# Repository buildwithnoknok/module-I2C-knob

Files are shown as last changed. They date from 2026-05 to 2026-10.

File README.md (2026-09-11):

# noknok Knob

An I²C-controlled rotary encoder module for the noknok ecosystem.
Designed for smooth, reliable user input: volume control, menu navigation, parameter adjustment, and more.

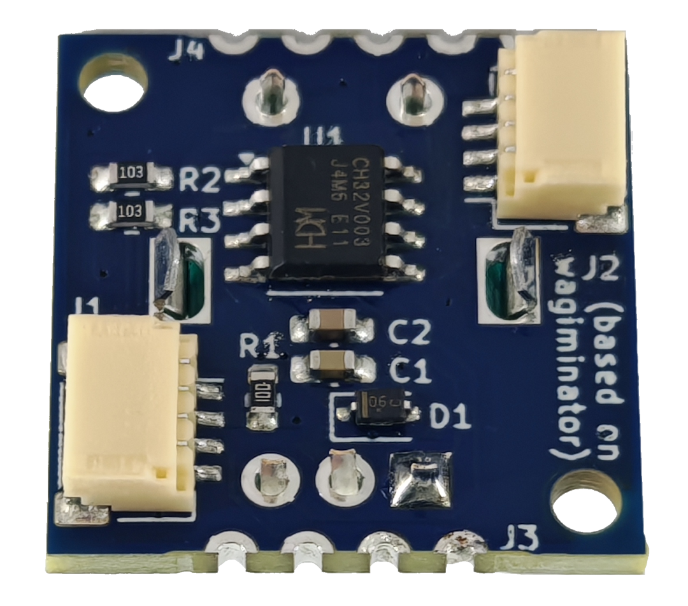
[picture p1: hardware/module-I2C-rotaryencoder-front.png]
Front

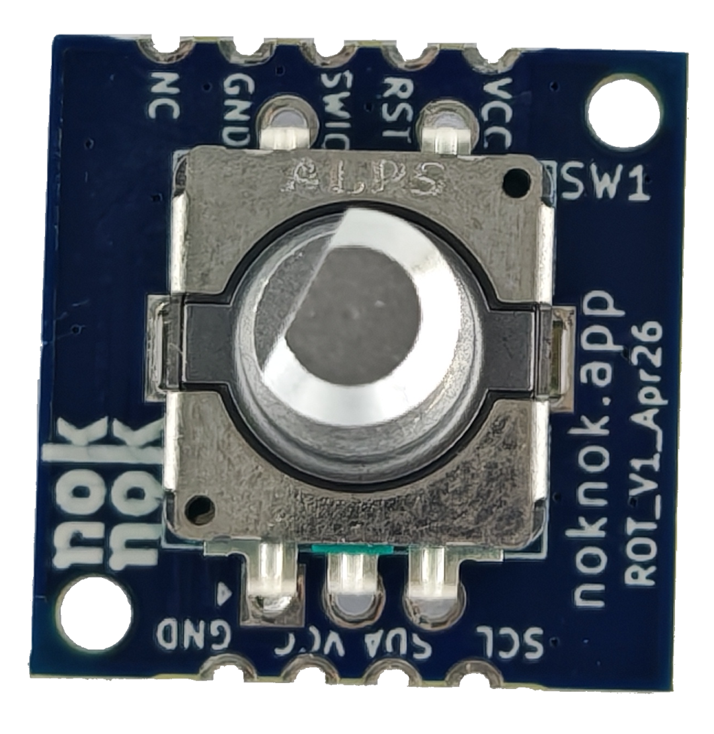
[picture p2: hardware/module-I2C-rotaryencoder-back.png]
Back


---

## Overview

The **noknok Knob** uses a CH32V003J4M6 microcontroller to read a mechanical EC11 rotary encoder with integrated push button. It exposes position, delta, and button state over I²C using the standard noknok JST SH 4-pin connector. The I²C address is assigned dynamically at boot by the noknok Conductor — no address conflicts when using multiple modules.

Typical use cases:
- Volume / brightness control
- Menu navigation
- Parameter tuning (speed, mode, color)
- General UI input for kits and finished products

---

## Hardware

| Property | Value |
|---|---|
| PCB size | 20 × 20 mm |
| MCU | CH32V003J4M6 (SOP-8) |
| Encoder | EC11 rotary encoder with push button |
| Connector | JST SH 4-pin (Qwiic / STEMMA QT compatible) |
| Supply voltage | 3.3 V |
| Logic voltage | 3.3 V |
| Hardware version | v2.0 |

### Pinout (CH32V003J4M6 SOP-8)

| Pin name | Function |
|---|---|
| PA2 | Encoder A (active LOW, internal pull-up) |
| PD6 / PA1 | Encoder B (active LOW, read as PA1) |
| PC4 | Push button S2 (active LOW; S1 and C are grounded) |
| PC1 | I²C SDA |
| PC2 | I²C SCL |
| PD1 / PD4 / PD5 | SWDIO — firmware flashing (3-pad pogo pads, J3) + status LED (D2, active LOW) share the PD1/SWIO net |

### noknok Connector (JST SH 4-pin)

| Pin | Signal |
|---|---|
| 1 | GND |
| 2 | 3.3 V |
| 3 | SDA |
| 4 | SCL |

---

## Firmware

**Version: v2.3.0 (bootloader‑hosted)**

### Enumeration

The module uses the standard noknok dynamic enumeration protocol — no hardcoded I²C address.

**→ Full protocol spec:** [Ecosystem / software / enumeration.md](https://github.com/buildwithnoknok/Ecosystem/blob/main/software/enumeration.md)

### I²C Protocol (normal operation)

**Pico reads 4 bytes:**

| Byte | Content |
|---|---|
| 0–1 | Signed 16-bit position, big-endian |
| 2 | Signed 8-bit delta since last read (auto-clears on read) |
| 3 | Button state: `0x01` = pressed, `0x00` = released |

> Button state is suppressed for 150 ms after any rotation to prevent false triggers from mechanical shaft coupling.

**Pico writes:**

| Command | Effect |
|---|---|
| `[0x10]` | Reset position to 0 |
| `[0x11, posH, posL]` | Set position to signed 16-bit value |
| `[0xB0]` | Enter bootloader — reset into the I²C bootloader for an OTA firmware update (see [Firmware](#firmware-1)) |
| `[0xB1]` | Get version — standard noknok command; the next read returns 4 version bytes (see below) |

**Version read** — `GET_VERSION` (`0xB1`) is a **noknok ecosystem-standard** command (the `0xB0`–`0xBF` range is reserved for standard commands across every module). Write `0xB1`, then read **4 bytes**: `[PROTOCOL_VERSION, FW_MAJOR, FW_MINOR, FW_PATCH]` = `[0x01, 2, 3, 0]`. Lets the Conductor compare the installed version against the version required by the product manifest. **→ Full spec:** [Ecosystem / software / readme.md §5](https://github.com/buildwithnoknok/Ecosystem/blob/main/software/readme.md#5-standard-system-commands)

### Encoder counting

- Hardware EXTI interrupts on both edges of PA1 and PA2 catch every quadrature transition immediately.
- A sub-step accumulator divides by 2: **2 raw transitions = 1 position count**, giving exactly **1 count per physical detent**.

---

## Python Driver

Part of the [noknok Ecosystem](https://github.com/buildwithnoknok/Ecosystem) — see `software/pico/noknok.py`.

```python
from noknok import Conductor

c = Conductor()
c.enumerate()                  # discovers all modules (~3 s)

knob = c.knob[0]               # first knob by discovery order
# or: knob = c.role["volume"]  # by role name after setup_roles()

s = knob.read()
if s is not None:
    print(s.position)          # signed int, cumulative turns
    print(s.delta)             # change since last read (auto-clears)
    print(s.pressed)           # True if button held down

knob.reset()                   # set position to 0
knob.set_position(50)          # set to any signed 16-bit value
```

---

## Firmware

**v2.3.0 runs under the shared noknok I²C bootloader** ([module-I2C-bootloader](https://github.com/buildwithnoknok/module-I2C-bootloader)) — the module can be re‑flashed **over the I²C bus** (no SWDIO cable in the field). The application is linked at the `0x1400` offset (`app.ld`) above the 5 KB stage-0 + stage-1 bootloader (layout 2) and reserves the top 16 B of RAM for the bootloader handoff cell. Command `0xB0` drops the running module into the bootloader for an update.

```bash
cd firmware/src
make build   # compile the offset-linked application -> knob_firmware.bin
```

> ch32fun must be installed at `../ch32fun/` relative to `firmware/src/` — see [cnlohr/ch32v003fun](https://github.com/cnlohr/ch32v003fun) for setup.

Flashing: normally over I²C from the Pico (`module_flasher.py` in `brain-Pico`). A blank board needs the bootloader SWD‑flashed once first. SWD remains the unbrickable backstop — see *Recovery & SWD flashing* in the [bootloader README](https://github.com/buildwithnoknok/module-I2C-bootloader#recovery--swd-flashing). `make flash` here still does a one‑off SWD flash of the app for bench bring‑up.

---

## Changelog

### v2.3.0 — app base 0x1400 (bootloader layout 2)
Relinked at the `0x1400` flash offset (bootloader **layout 2**: 1 KB stage-0 + 4 KB stage-1 below the app; was `0x1000`). Firmware behaviour unchanged. **Not compatible with the legacy monolithic bootloader or a layout-1 stage-1** — such a module gets stage-0 + stage-1 v1.1.0 over SWD first, then this app over I²C. See [module-I2C-bootloader](https://github.com/buildwithnoknok/module-I2C-bootloader).

### v2.2.0 — watchdog + boot-health handshake (DEV-31)
Runs the independent watchdog (~2 s, kicked every main-loop pass) and writes `0` to `0x200007F8` the moment its I²C address is assigned — the app-health handshake with the stage-1 bootloader. Stage-1 counts watchdog resets and parks the module (error 7, rescued by the Conductor by UID) after three in a row, instead of booting a broken app forever. Contract: [Ecosystem / software / bootloader-update.md §3](https://github.com/buildwithnoknok/Ecosystem/blob/main/software/bootloader-update.md). No protocol or command change.

### v2.1 and earlier
See the git history.

## Status

| Item | Status |
|---|---|
| Hardware | v2.0 complete |
| Firmware | v2.3.0 complete (bootloader‑hosted, I²C OTA) |
| Python driver | Complete (`NoknokKnob` in [Ecosystem repo](https://github.com/buildwithnoknok/Ecosystem/tree/main/software/pico)) |
| Documentation | Complete |

---

## License

- Firmware / code: MIT — see [LICENSE](LICENSE).
- Hardware (schematics, PCB layout, fab files): CC BY-SA 4.0 — see [LICENSE-hardware](LICENSE-hardware).

## Trademarks

**noknok** is a registered trademark in Switzerland (Swissreg 1300007033).

Qwiic is a registered trademark of SparkFun Electronics, Inc. STEMMA QT is a
trademark of Adafruit Industries, LLC. Both are named here only to state
connector compatibility - noknok is not affiliated with, endorsed by, or
sponsored by either company.
---

---

## Safety & Liability

noknok hardware is an electronic device and a DIY/maker kit. You assemble, modify, flash, power, and operate it at your own risk, and it is provided as is, without warranty. See the full notice: [License, Safety & Liability](https://buildwithnoknok.github.io/safety-and-license/).

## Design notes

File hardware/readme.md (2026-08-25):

# Hardware — noknok Knob

Hardware design files for the noknok Knob module (CH32V003J4M6 — I2C rotary encoder with integrated push button).

- KiCad project: `kicad/I2C_knob.*`
- Schematic (PDF): `module-I2C-knob-Schematics.pdf`
- BOM: `module_I2C-knob-BOM.xls`
- Board renders: `module-I2C-rotaryencoder-front.png`, `module-I2C-rotaryencoder-back.png` *(pre-V2 renders — pending re-export)*

Hardware is licensed CC BY-SA 4.0 (see `../LICENSE-hardware`). Connector, flashing and mounting standards follow the [noknok Ecosystem guidelines](https://github.com/buildwithnoknok/Ecosystem) (electrical + mechanical).

---

## Hardware Change Record

### v2.0 — changes from v1.0
- **Status indicator LED on PD1** (in parallel with the SWIO flashing line — zero extra GPIO). Active-low: `+3V3_PROT → R2 (2.2 kΩ) → D2 anode; D2 cathode → PD1/SWIO`. Driven by the bootloader (off = app running, slow pulse = updating/recovering, solid = error). Parts: red 0603 LED (LCSC C2286) + 2.2 kΩ 0603 (LCSC C4190).
- **Removed both castellated edge pads** — the 5-pin flashing edge and the redundant I2C edge (unreliable to contact). I2C is via the JST-SH (Qwiic) connectors J1/J2 only.
- **New flashing interface (J3)** — noknok flash pads (`noknok_FlashPads_I2C-module_1x3_M2.5`): 3 single-side SMD pogo pads (GND / SWIO / VCC) plus an embedded M2.5 keyed mounting hole, from the noknok KiCad library in the Ecosystem repo. Pad row is offset toward the keyed hole (not centered) so a 180°-flipped clamp contact can't seat and reverse-power the board.
- **Second mounting hole (H1)** — plain `noknok_MountingHole_2.5mm_M2.5`, diagonally opposite the flash-pad hole, center (2.25, 2.25) mm from the board corner.
- **Removed the on-board I²C pull-up resistors** (previously R2/R3) — pull-ups now live on the host (Conductor), not per module (avoids stacking on the shared bus). The host must provide the bus pull-ups (proposed 3.3 kΩ); a noknok pull-up PCB covers third-party hosts that lack them. See the [I²C Pull-up Resistor Strategy ADR](https://noknokdev.atlassian.net/wiki/spaces/SD/pages/82280449). *(Note: `R2` is reused below for the new status-LED resistor — it is not the old pull-up.)*
- **R1 (VDD series) stays 10 Ω** — the knob has no spiky load on VDD (unlike the buzzer's beep-current 10Ω→1Ω fix), so the standard default is unchanged.

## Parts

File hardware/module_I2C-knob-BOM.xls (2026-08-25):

Item # | *Designator | *Qty | Manufacturer | *Mfg Part # | Description / Value | Vendor Part # | *Package/Footprint | Substitute
1 | C1 | 1 | YAGEO | CC0603MRX5R8BB106 | 10uF / CAP CER 10uF 25V X5R 0603 | C596327 | C_0603_1608Metric_Pad1.08x0.95mm_HandSolder | SAMSUNG『 』CL10A106KP8NNNC『 』C19702
2 | C2 | 1 | YAGEO | CC0603KRX7R9BB104 | 0.1uF / CAP CER 100nF 50V X7R 0603 | C14663 | C_0603_1608Metric_Pad1.08x0.95mm_HandSolder | SAMSUNG『 』CL10B104KA8NNNC『 』C1590
3 | D1 | 1 | onsemi | MM3Z3V6T1G | D_Zener | C116949 | D_SOD-323 | ROHM『 』UDZVTE-173.6B『 』C209558
4 | D2 | 1 | Hubei KENTO Elec | KT-0603R | LED RED WATER CLEAR 0603 SMD | C2286 | 0603
5 | J1, J2 | 2 | JST | SM04B-SRSS-TB(LF)(SN) | JST 4 Pin Qwiic I2C Connector | C160404 | JST_SH_SM04B-SRSS-TB_1x04-1MP_P1.00mm_Horizontal
6 | R1 | 1 | YAGEO | RC0603JR-0710RL | 10R | C109317 | R_0603_1608Metric | Viking『 』ARG03FTC0100『 』C217691
7 | R2 | 1 | YAGEO | RC0603JR-072K2L | 2.2k | C113303 | R_0603_1608Metric | Viking『 』ARG03FTC2201『 』C217937
8 | SW1 | 1 | ALPSALPINE | EC11E18244AU | RotaryEncoder_Switch | C202365 | RotaryEncoder_Alps_EC11E-Switch_Vertical_H20mm
9 | U1 | 1 | WCH(Jiangsu Qin Heng) | CH32V003J4M6 | CH32V003J4M6 | C5346354 | JEITA_SOIC-8_3.9x4.9mm_P1.27mm

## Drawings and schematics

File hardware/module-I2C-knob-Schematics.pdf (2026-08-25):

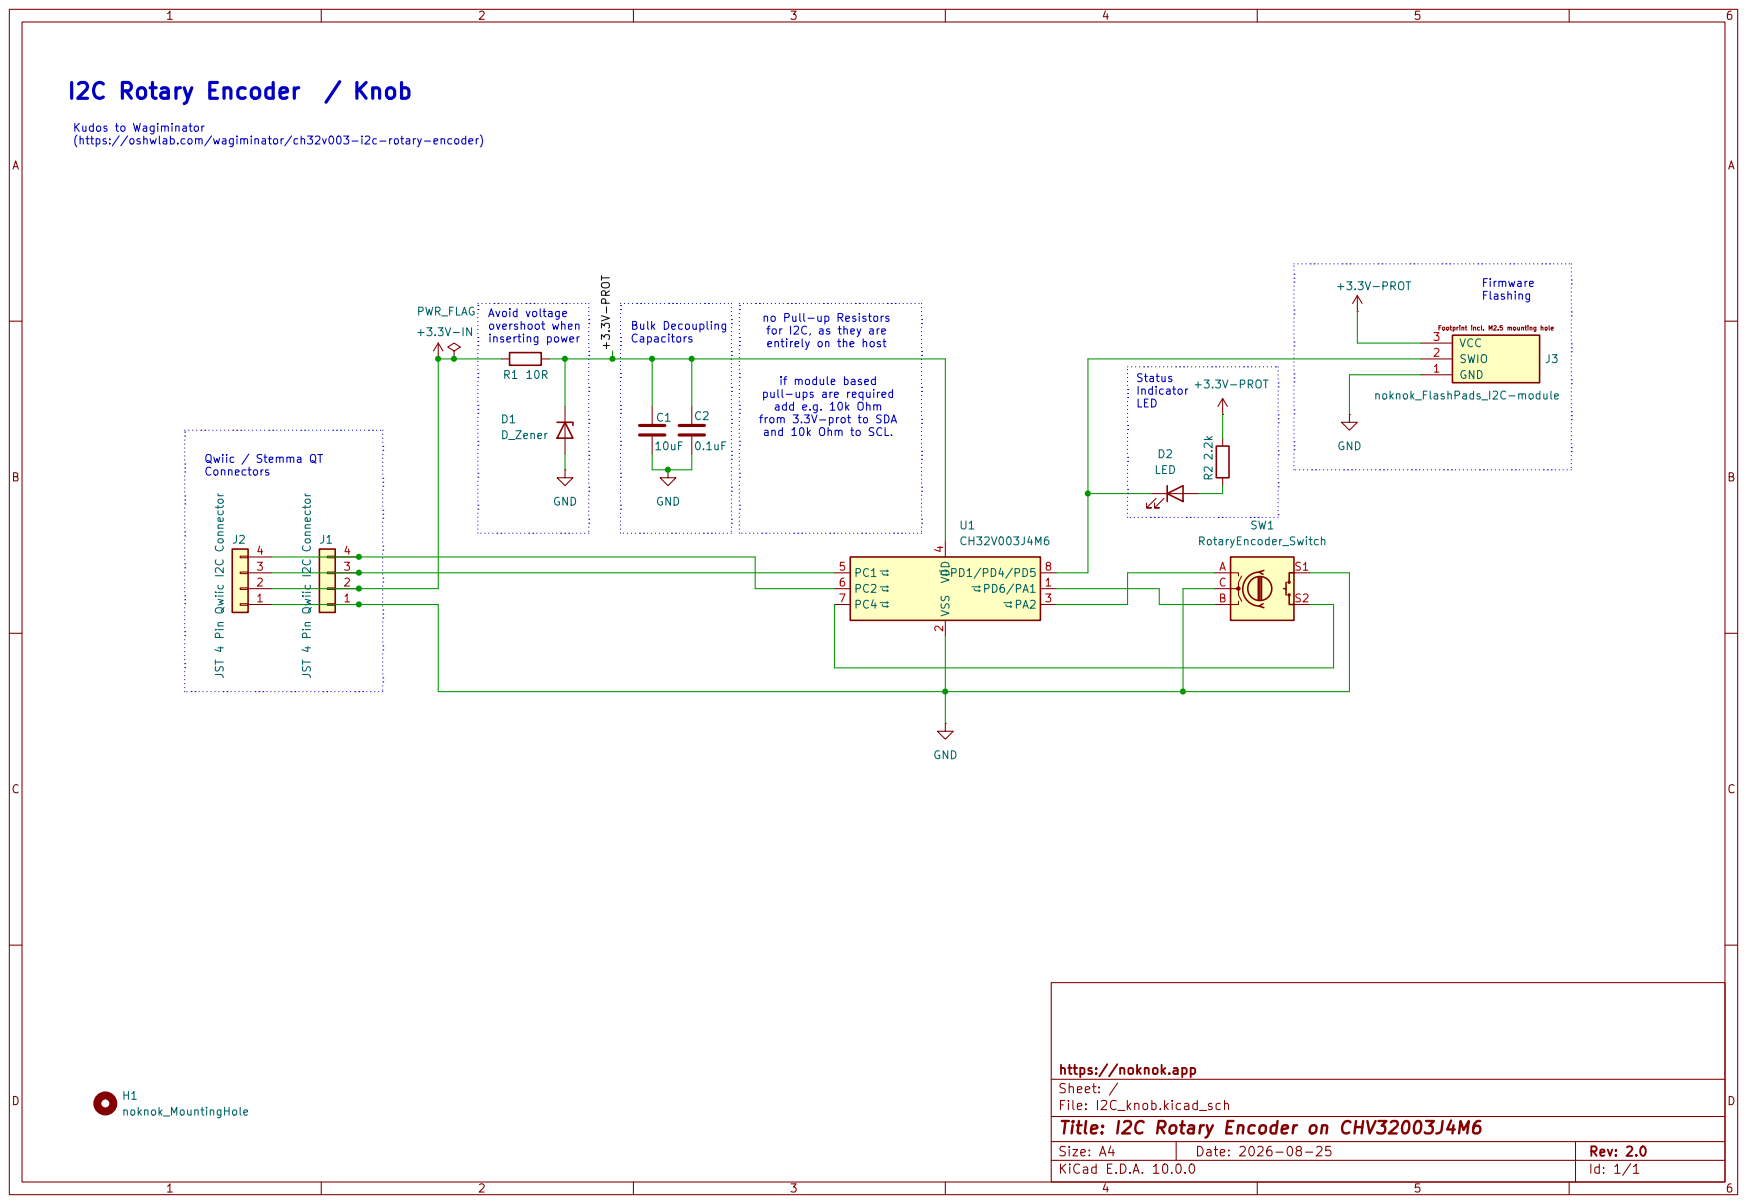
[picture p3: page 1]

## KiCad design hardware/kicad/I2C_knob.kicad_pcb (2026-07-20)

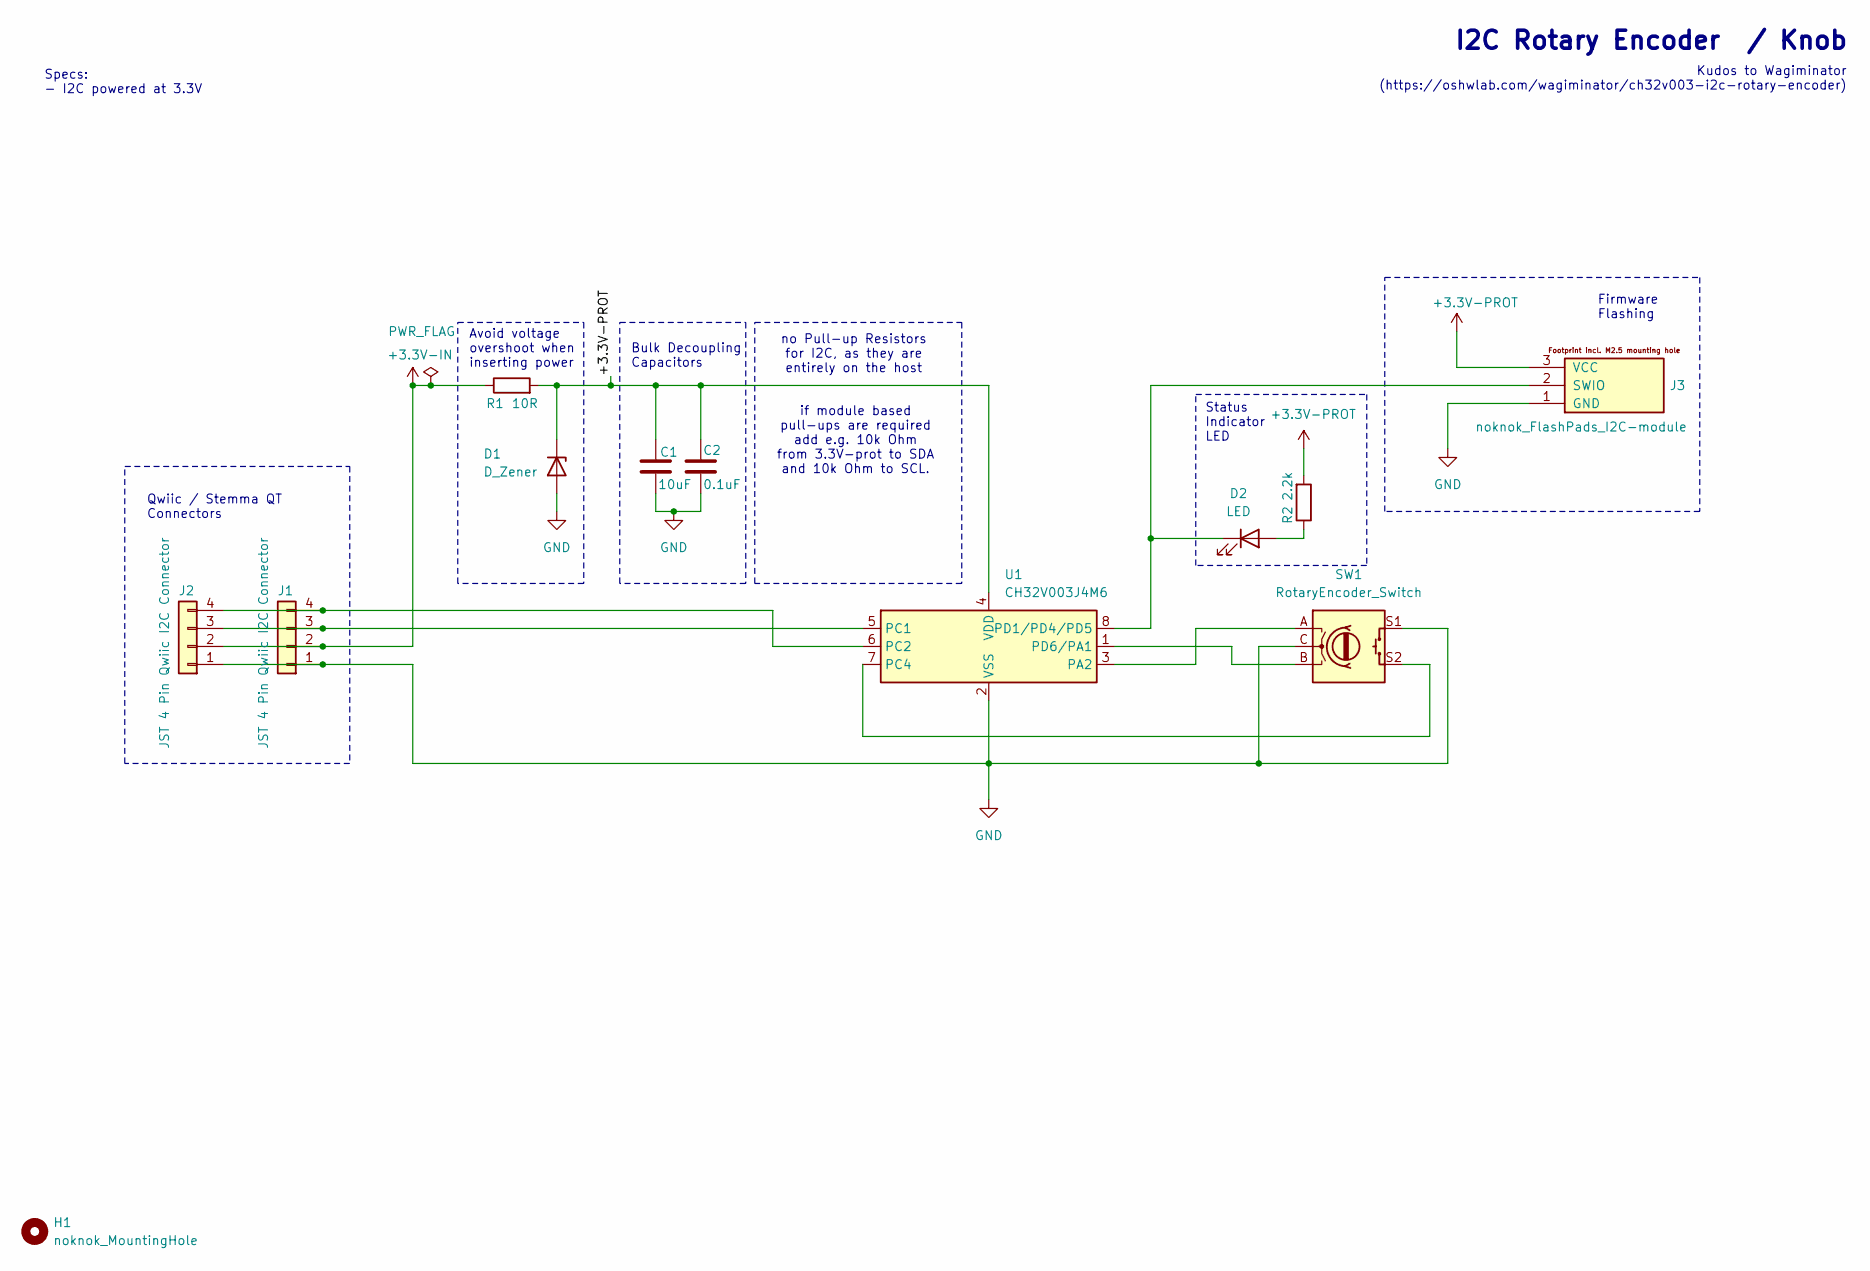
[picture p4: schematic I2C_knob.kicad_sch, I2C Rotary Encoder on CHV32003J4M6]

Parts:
C1: 10uF; C_0603_1608Metric_Pad1.08x0.95mm_HandSolder
C2: 0.1uF; C_0603_1608Metric_Pad1.08x0.95mm_HandSolder
D1: D_Zener; D_SOD-323
D2: LED; LED_0603_1608Metric
H1: noknok_MountingHole; noknok_MountingHole_2.5mm_M2.5
J1, J2: JST 4 Pin Qwiic I2C Connector; JST_SH_SM04B-SRSS-TB_1x04-1MP_P1.00mm_Horizontal
J3: noknok_FlashPads_I2C-module; noknok_FlashPads_I2C-module_1x3_M2.5
R1: 10R; R_0603_1608Metric
R2: 2.2k; R_0603_1608Metric
SW1: RotaryEncoder_Switch; RotaryEncoder_Alps_EC11E-Switch_Vertical_H20mm
U1: CH32V003J4M6; JEITA_SOIC-8_3.9x4.9mm_P1.27mm

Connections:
+3.3V-IN: J1.2, J2.2, R1.1
+3.3V-PROT: C1.1, C2.1, D1.1 (K), J3.3 (VCC), R1.2, R2.2, U1.4 (VDD)
GND: C1.2, C2.2, D1.2 (A), J1.1, J2.1, J3.1 (GND), SW1.C, SW1.S1, U1.2 (VSS)
unnamed: D2.2 (A), R2.1
unnamed: D2.1 (K), J3.2 (SWIO), U1.8 (PD1/PD4/PD5)
unnamed: J1.3, J2.3, U1.5 (PC1)
unnamed: J1.4, J2.4, U1.6 (PC2)
unnamed: SW1.A, U1.3 (PA2)
unnamed: SW1.S2, U1.7 (PC4)
unnamed: SW1.B, U1.1 (PD6/PA1)

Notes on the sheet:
Avoid voltage overshoot when inserting power
Specs: - I2C powered at 3.3V
I2C Rotary Encoder / Knob
if module based pull-ups are required add e.g. 10k Ohm from 3.3V-prot to SDA and 10k Ohm to SCL.
Status Indicator LED
no Pull-up Resistors for I2C, as they are entirely on the host
Firmware Flashing
Qwiic / Stemma QT Connectors
Kudos to Wagiminator (https://oshwlab.com/wagiminator/ch32v003-i2c-rotary-encoder)
Bulk Decoupling Capacitors

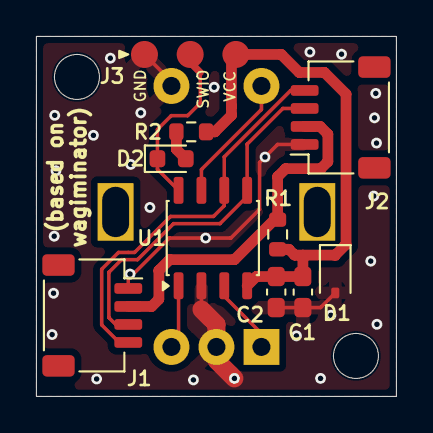
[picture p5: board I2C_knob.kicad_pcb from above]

Board: 2 copper layers, 20.0 x 20.0 mm, 12 parts (1 on the bottom side), 10 nets.

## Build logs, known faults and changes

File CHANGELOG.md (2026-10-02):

# Changelog - noknok Knob module firmware

Newest first. One entry per version bump, written in the same commit as the bump. Format:
`## <version> - <date>` then `- DEV-xx - what changed and why. Breaking: yes/no.`
Convention: Confluence "Development Conventions" (SD space, page 120160257).

## Baseline - 2026-10-02

- Changelog starts here. Current: knob firmware 2.3.0 (released 2026-09-11). Earlier history: git log and the README.

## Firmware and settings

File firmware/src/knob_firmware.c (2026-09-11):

/*
 * noknok Knob Module Firmware  v2.2.0
 *
 * v2.2.0: DEV-31 hardening C — independent watchdog + boot-attempt handshake
 *   with stage-1 (clears the counter once an I2C address is assigned).
 * CH32V003J4M6 (SOP-8)  |  Stack: cnlohr/ch32fun
 *
 * ── Hardware ─────────────────────────────────────────────────────────────
 *   PA2          Encoder A (active LOW, internal pull-up)
 *   PD6/PA1      Encoder B (active LOW, internal pull-up; read as PA1 via GPIOA)
 *   PC4          Encoder push button S2 (active LOW; S1 and C are grounded)
 *   PC1          I2C SDA
 *   PC2          I2C SCL
 *
 * ── Encoder counting ─────────────────────────────────────────────────────
 *   EXTI interrupts on both edges of PA1 and PA2 (EXTI1 + EXTI2, port A).
 *   Gray-code lookup table → ±1 per quadrature transition.
 *   A standard EC11 with 4 pulses/detent gives 4 counts per click.
 *
 * ── Button behaviour ─────────────────────────────────────────────────────
 *   50 ms debounce. Suppressed for 150 ms after any rotation (mechanical
 *   coupling between shaft and SW pin causes false triggers during turns).
 *
 * ── Enumeration protocol ─────────────────────────────────────────────────
 *   Identical to noknok Buzzer v3.1.
 *   Staging address : 0x7F
 *   Runtime address : assigned by Conductor (0x08–0x77)
 *
 *   1. Conductor reads 10 bytes from 0x7F:
 *        [UID 0..7]   64-bit hardware UID
 *        [0x02]       MODULE_TYPE (knob)
 *        [CRC8]       CRC8 of bytes 0–8
 *
 *   2. Conductor writes to 0x7F:
 *        [0x1D, new_addr]   ASSIGN — module switches to new_addr
 *
 * ── Normal operation protocol ────────────────────────────────────────────
 *   I2C address: assigned at runtime
 *
 *   Pico READS 4 bytes:
 *     [posH, posL]   signed 16-bit position, big-endian
 *     [delta]        signed 8-bit change since last read (auto-cleared)
 *     [btn_state]    0x01 if button pressed, 0x00 if released
 *                    Always 0x00 within 150 ms of rotation.
 *
 *   Pico WRITES:
 *     [0x10]              RESET — set position to 0
 *     [0x11, posH, posL]  SET POSITION — set position to given value
 *     [0xB0]              ENTER BOOTLOADER (I2C OTA update)
 *     [0xB1]              GET VERSION — next read returns 4 version bytes
 *
 *   Pico READS (after 0xB1):
 *     4 bytes: [PROTOCOL_VER, FW_MAJOR, FW_MINOR, FW_PATCH]
 *
 *   GET_VERSION (0xB1) is a noknok ecosystem-standard command (range
 *   0xB0–0xBF reserved). See Ecosystem/software/readme.md §5.
 */

#include "ch32fun.h"
#include <stdint.h>

/* ═══════════════════════════════════════════════════════════════════════════
 * CONFIGURATION
 * ═══════════════════════════════════════════════════════════════════════════ */

#define ENUM_ADDR       0x7F
#define MODULE_TYPE     0x02    /* 0x02 = Rotary Encoder / Knob */
#define REG_ASSIGN_ADDR 0x1D
#define CMD_RESET_POS   0x10
#define CMD_SET_POS     0x11
#define CMD_ENTER_BOOTLOADER 0xB0   /* reset into the I2C bootloader for OTA update */
#define CMD_GET_VERSION 0xB1        /* report [PROTOCOL_VERSION, FW_MAJOR, FW_MINOR, FW_PATCH] */

/* ── Version reporting (noknok standard command, DEV-1) ──────────────────────
 * PROTOCOL_VERSION = which noknok protocol/API this module speaks — NOT the
 * firmware version. Bumped only when the shared protocol changes. The
 * FW_VERSION_* triple is this module's firmware semver; keep it equal to the
 * release tag. Reported on a GET_VERSION (0xB1) read. */
#define PROTOCOL_VERSION 0x01
#define FW_VERSION_MAJOR 2
#define FW_VERSION_MINOR 3
#define FW_VERSION_PATCH 0

/* Bootloader handoff cell — top 16 B of RAM, reserved by app.ld (stack ends
 * below it). Writing this magic then warm-resetting drops the module into the
 * shared noknok I2C bootloader (flash mode at 0x7E). SRAM survives a warm reset.
 * Magic + address MUST match noknok_bootloader. */
#define BL_MAGIC_CELL   (*(volatile uint32_t *)0x200007F0U)
#define BL_MAGIC_ENTER  0x6E6B4231U   /* "nkB1" */

/* ── App health handshake with stage-1 (DEV-31 hardening C) ──────────────────
 * Stage-1 counts every boot of this app in a no-init RAM cell and stops booting
 * it after three consecutive warm resets without the app ever proving itself,
 * parking the module in the bootloader at 0x7E so the host can push a good
 * image instead. That turns "a broken app with a valid CRC is booted forever"
 * into "a broken app gets three tries". Two things make it work here:
 *   - the independent watchdog, so a hang becomes a warm reset (~2 s), and
 *   - clearing the counter the moment we KNOW we are healthy: an I2C address
 *     has been assigned, i.e. enumeration completed, i.e. I2C works.
 * Address and tag must match noknok_stage1. */
#define BOOT_ATTEMPT_CELL (*(volatile uint32_t *)0x200007F8U)

static void iwdg_init(void)
{
    /* LSI ~128 kHz / 64 = 2 kHz; reload 4095 -> ~2.05 s. Hardware starts LSI. */
    IWDG->CTLR = 0x5555;  IWDG->PSCR = 4;
    IWDG->CTLR = 0x5555;  IWDG->RLDR = 0xFFF;
    IWDG->CTLR = 0xCCCC;  /* start — cannot be stopped except by reset */
}
static inline void iwdg_kick(void) { IWDG->CTLR = 0xAAAA; }

#define UID_ADDR        ((volatile uint8_t*)0x1FFFF7E8)
#define UID_LEN         8

#define BTN_DEBOUNCE_MS         50
#define BTN_ROTATION_LOCKOUT_MS 150


/* ═══════════════════════════════════════════════════════════════════════════
 * STATE
 * ═══════════════════════════════════════════════════════════════════════════ */

typedef enum {
    DEV_BOOT_WAITING,
    DEV_ENUM_READY,
    DEV_ASSIGNING,
    DEV_ASSIGNED,
} DeviceState;

static volatile DeviceState dev_state = DEV_BOOT_WAITING;
static volatile uint32_t    ms_tick   = 0;
static volatile uint8_t     new_addr  = 0;
static volatile uint8_t     version_pending = 0; /* set in ISR on 0xB1; next read returns version */

/* Encoder */
static volatile int16_t  enc_position    = 0;
static volatile int8_t   enc_delta       = 0;
static volatile uint32_t last_rotation_ms = 0;
static volatile uint8_t  enc_last_ab     = 0;
static volatile int8_t   enc_sub         = 0;  /* sub-step: 2 raw transitions = 1 count */

/* Lookup table: enc_table[(prev<<2)|curr] → +1, -1, or 0 */
static const int8_t enc_table[16] = {
     0, -1,  1,  0,
     1,  0,  0, -1,
    -1,  0,  0,  1,
     0,  1, -1,  0
};

/* Button */
static volatile uint8_t  btn_state        = 0;
static          uint8_t  btn_raw_last      = 0;
static          uint32_t btn_last_change_ms = 0;

/* I2C receive */
#define RX_BUF_SIZE 8
static volatile uint8_t rx_buf[RX_BUF_SIZE];
static volatile uint8_t rx_len    = 0;
static volatile uint8_t cmd_ready = 0;

/* I2C transmit */
#define TX_BUF_SIZE 10
static volatile uint8_t tx_buf[TX_BUF_SIZE];
static volatile uint8_t tx_len = 0;
static volatile uint8_t tx_idx = 0;

/* Backoff */
static uint32_t backoff_ms;
static uint32_t enum_ready_start_ms = 0;


/* ═══════════════════════════════════════════════════════════════════════════
 * CRC8  (polynomial 0x07)
 * ═══════════════════════════════════════════════════════════════════════════ */

static uint8_t crc8(const uint8_t *data, uint8_t len)
{
    uint8_t crc = 0x00;
    for (uint8_t i = 0; i < len; i++) {
        crc ^= data[i];
        for (uint8_t j = 0; j < 8; j++)
            crc = (crc & 0x80) ? (crc << 1) ^ 0x07 : (crc << 1);
    }
    return crc;
}


/* ═══════════════════════════════════════════════════════════════════════════
 * BACKOFF TIMER  —  proper FNV-1a, identical to Buzzer v3.1
 * ═══════════════════════════════════════════════════════════════════════════ */

static uint32_t fnv_hash(uint32_t h)
{
    volatile uint8_t *uid = UID_ADDR;
    for (uint8_t i = 0; i < UID_LEN; i++) {
        h ^= uid[i];
        h *= 16777619UL;
    }
    return h;
}

static void calc_backoff(void)
{
    backoff_ms = (fnv_hash(2166136261UL) % 2500) + 300;
}

static uint32_t calc_rebackoff_ms(void)
{
    return ms_tick + (fnv_hash(ms_tick) % 500) + 50;
}


/* ═══════════════════════════════════════════════════════════════════════════
 * BUILD RESPONSES
 * ═══════════════════════════════════════════════════════════════════════════ */

static void build_uid_response(void)
{
    volatile uint8_t *uid = UID_ADDR;
    for (uint8_t i = 0; i < UID_LEN; i++)
        tx_buf[i] = uid[i];
    tx_buf[8] = MODULE_TYPE;
    tx_buf[9] = crc8((const uint8_t*)tx_buf, 9);
    tx_len = 10;
    tx_idx = 0;
}

static void build_data_response(void)
{
    int16_t pos = enc_position;

    /* Read enc_delta and clear it atomically here in the ISR.
     * Clearing here (not in the main loop) prevents a race where encoder
     * transitions arriving between this read and a deferred main-loop clear
     * would be silently discarded. Any transitions after this point will
     * correctly accumulate into enc_delta for the next read. */
    int8_t dlt  = enc_delta;
    enc_delta   = 0;

    /* Suppress button during rotation lockout — shaft mechanics couple into SW */
    uint8_t btn = ((ms_tick - last_rotation_ms) >= BTN_ROTATION_LOCKOUT_MS)
                  ? btn_state : 0;
    tx_buf[0] = (uint8_t)((pos >> 8) & 0xFF);
    tx_buf[1] = (uint8_t)(pos & 0xFF);
    tx_buf[2] = (uint8_t)dlt;
    tx_buf[3] = btn;
    tx_len = 4;
    tx_idx = 0;
}

/* 4-byte GET_VERSION response: [PROTOCOL_VERSION, FW_MAJOR, FW_MINOR, FW_PATCH] */
static void build_version_response(void)
{
    tx_buf[0] = PROTOCOL_VERSION;
    tx_buf[1] = FW_VERSION_MAJOR;
    tx_buf[2] = FW_VERSION_MINOR;
    tx_buf[3] = FW_VERSION_PATCH;
    tx_len = 4;
    tx_idx = 0;
}


/* ═══════════════════════════════════════════════════════════════════════════
 * GPIO INIT
 * ═══════════════════════════════════════════════════════════════════════════ */

static void encoder_gpio_init(void)
{
    RCC->APB2PCENR |= RCC_APB2Periph_GPIOA | RCC_APB2Periph_GPIOC;

    /* PA1 (ENC_B) and PA2 (ENC_A): input with pull-up */
    GPIOA->CFGLR &= ~((0xF << (1 * 4)) | (0xF << (2 * 4)));
    GPIOA->CFGLR |=  ((0x8 << (1 * 4)) | (0x8 << (2 * 4)));
    GPIOA->BSHR   =  (1 << 1) | (1 << 2);

    /* PC4: input with pull-up (button S2, active LOW; S1+C are grounded) */
    GPIOC->CFGLR &= ~(0xF << (4 * 4));
    GPIOC->CFGLR |=  (0x8 << (4 * 4));
    GPIOC->BSHR   =  (1 << 4);
}

static inline uint8_t read_enc_ab(void)
{
    /* A = PA2 (active low), B = PA1 (active low) — per Wagiminator reference.
     * Invert both so 1 means "encoder contact closed". */
    uint8_t a = !((GPIOA->INDR >> 2) & 1);   /* PA2 = ENC_A */
    uint8_t b = !((GPIOA->INDR >> 1) & 1);   /* PA1 = ENC_B */
    return (a << 1) | b;
}

static inline uint8_t read_btn_raw(void)
{
    return ((GPIOC->INDR >> 4) & 1) ? 0 : 1;   /* PC4, active LOW */
}


/* ═══════════════════════════════════════════════════════════════════════════
 * EXTI  —  hardware interrupts on both edges of PA1 (EXTI1) and PA2 (EXTI2)
 *   Catches every quadrature transition immediately, regardless of main loop
 *   speed. Both EXTI1 and EXTI2 share EXTI7_0_IRQn on CH32V003.
 * ═══════════════════════════════════════════════════════════════════════════ */

static void exti_encoder_init(void)
{
    RCC->APB2PCENR |= RCC_APB2Periph_AFIO;

    /* Route EXTI1 and EXTI2 to port A (bits [3:2] and [5:4] = 00 = PA) */
    AFIO->EXTICR &= ~((0x3 << 2) | (0x3 << 4));

    /* Enable interrupts on both rising and falling edges for EXTI1 and EXTI2 */
    EXTI->INTENR |= (1 << 1) | (1 << 2);
    EXTI->RTENR  |= (1 << 1) | (1 << 2);
    EXTI->FTENR  |= (1 << 1) | (1 << 2);

    NVIC_EnableIRQ(EXTI7_0_IRQn);
}

void EXTI7_0_IRQHandler(void) __attribute__((interrupt));
void EXTI7_0_IRQHandler(void)
{
    if (EXTI->INTFR & ((1 << 1) | (1 << 2)))
    {
        uint8_t ab  = read_enc_ab();
        uint8_t idx = (enc_last_ab << 2) | ab;
        int8_t  dir = enc_table[idx];

        if (dir != 0)
        {
            last_rotation_ms = ms_tick;
            enc_sub += dir;
            if (enc_sub >= 2)      { enc_sub -= 2; enc_position++; enc_delta++; }
            else if (enc_sub <= -2){ enc_sub += 2; enc_position--; enc_delta--; }
        }

        enc_last_ab = ab;
        EXTI->INTFR = (1 << 1) | (1 << 2);   /* clear pending flags */
    }
}


/* ═══════════════════════════════════════════════════════════════════════════
 * TIM2  —  1 ms tick
 * ═══════════════════════════════════════════════════════════════════════════ */

static void tim2_init(void)
{
    RCC->APB1PCENR |= RCC_APB1Periph_TIM2;
    TIM2->PSC      = 47;
    TIM2->ATRLR    = 999;
    TIM2->DMAINTENR = TIM_IT_Update;
    TIM2->SWEVGR   = TIM_UG;
    TIM2->CTLR1   |= TIM_CEN;
    NVIC_EnableIRQ(TIM2_IRQn);
}

void TIM2_IRQHandler(void) __attribute__((interrupt));
void TIM2_IRQHandler(void) { TIM2->INTFR = 0; ms_tick++; }


/* ═══════════════════════════════════════════════════════════════════════════
 * I2C SLAVE
 * ═══════════════════════════════════════════════════════════════════════════ */

static void i2c_slave_init(uint8_t addr)
{
    RCC->APB2PCENR |= RCC_APB2Periph_GPIOC;
    RCC->APB1PCENR |= RCC_APB1Periph_I2C1;

    GPIOC->CFGLR &= ~(0xF << (1 * 4)); GPIOC->CFGLR |= (0xF << (1 * 4));
    GPIOC->CFGLR &= ~(0xF << (2 * 4)); GPIOC->CFGLR |= (0xF << (2 * 4));

    I2C1->CTLR1 |=  I2C_CTLR1_SWRST;
    I2C1->CTLR1 &= ~I2C_CTLR1_SWRST;

    I2C1->CTLR2  = 48;
    I2C1->CKCFGR = 240;
    I2C1->OADDR1 = ((uint16_t)addr << 1);

    I2C1->CTLR2 |= I2C_CTLR2_ITEVTEN | I2C_CTLR2_ITBUFEN | I2C_CTLR2_ITERREN;
    I2C1->CTLR1 |= I2C_CTLR1_ACK | I2C_CTLR1_PE;

    NVIC_EnableIRQ(I2C1_EV_IRQn);
    NVIC_EnableIRQ(I2C1_ER_IRQn);
}

static void i2c_switch_addr(uint8_t addr)
{
    I2C1->CTLR1 &= ~I2C_CTLR1_PE;
    I2C1->OADDR1 = ((uint16_t)addr << 1);
    I2C1->CTLR1 |= I2C_CTLR1_ACK | I2C_CTLR1_PE;
}


/* ═══════════════════════════════════════════════════════════════════════════
 * I2C EVENT ISR
 * ═══════════════════════════════════════════════════════════════════════════ */

void I2C1_EV_IRQHandler(void) __attribute__((interrupt));
void I2C1_EV_IRQHandler(void)
{
    uint32_t star1 = I2C1->STAR1;
    uint32_t star2 = I2C1->STAR2;

    if (star1 & I2C_STAR1_ADDR)
    {
        rx_len = 0;
        I2C1->CTLR1 |= I2C_CTLR1_ACK;

        if (star2 & I2C_STAR2_TRA)
        {
            if (dev_state == DEV_ENUM_READY)
            {
                build_uid_response();
                I2C1->DATAR = tx_buf[tx_idx++];
            }
            else if (version_pending)
            {
                /* Previous write was GET_VERSION → return the 4 version bytes */
                version_pending = 0;
                build_version_response();
                I2C1->DATAR = tx_buf[tx_idx++];
            }
            else
            {
                build_data_response();
                I2C1->DATAR = tx_buf[tx_idx++];
            }
        }
        return;
    }

    if (star1 & I2C_STAR1_RXNE)
    {
        uint8_t b = (uint8_t)I2C1->DATAR;
        if (rx_len < RX_BUF_SIZE) rx_buf[rx_len++] = b;
        return;
    }

    if (star1 & I2C_STAR1_TXE)
    {
        I2C1->DATAR = (tx_idx < tx_len) ? tx_buf[tx_idx++] : 0x00;
        return;
    }

    if (star1 & I2C_STAR1_STOPF)
    {
        I2C1->CTLR1 |= I2C_CTLR1_PE;

        if (dev_state == DEV_ENUM_READY)
        {
            if (rx_len == 2 && rx_buf[0] == REG_ASSIGN_ADDR)
            {
                new_addr  = rx_buf[1];
                dev_state = DEV_ASSIGNING;
            }
        }
        else if (dev_state == DEV_ASSIGNED)
        {
            /* GET_VERSION is handled entirely in the ISR: latch it so the next
             * read returns the version bytes. Don't route it to the main loop. */
            if (rx_len == 1 && rx_buf[0] == CMD_GET_VERSION)
                version_pending = 1;
            else if (rx_len > 0)
                cmd_ready = 1;
        }

        I2C1->CTLR1 |= I2C_CTLR1_ACK;
        return;
    }
}

void I2C1_ER_IRQHandler(void) __attribute__((interrupt));
void I2C1_ER_IRQHandler(void)
{
    I2C1->STAR1 &= ~(I2C_STAR1_BERR | I2C_STAR1_ARLO |
                     I2C_STAR1_AF   | I2C_STAR1_OVR);
    I2C1->CTLR1 |= I2C_CTLR1_ACK;
}


/* ═══════════════════════════════════════════════════════════════════════════
 * COMMAND PROCESSOR
 * ═══════════════════════════════════════════════════════════════════════════ */

static void process_command(void)
{
    uint8_t cmd = rx_buf[0];

    if (cmd == CMD_RESET_POS)
    {
        enc_position = 0;
        enc_delta    = 0;
    }
    else if (cmd == CMD_SET_POS && rx_len >= 3)
    {
        int16_t new_pos = ((int16_t)rx_buf[1] << 8) | rx_buf[2];
        enc_delta    += (new_pos - enc_position);
        enc_position  = new_pos;
    }
    else if (cmd == CMD_ENTER_BOOTLOADER)
    {
        /* OTA update requested: arm the handoff magic and warm-reset into the
         * bootloader (0x7E). NVIC_SystemReset() does not clear SRAM. */
        BL_MAGIC_CELL = BL_MAGIC_ENTER;
        NVIC_SystemReset();
    }
}


/* ═══════════════════════════════════════════════════════════════════════════
 * BUTTON POLL  —  debounced, called from main loop
 *   During rotation lockout: force btn_state=0 and reset debounce tracker
 *   so the button must re-debounce from scratch after every turn ends.
 *   This prevents the SW pin's mechanical coupling from causing false presses.
 * ═══════════════════════════════════════════════════════════════════════════ */

static void poll_button(void)
{
    uint8_t  raw = read_btn_raw();
    uint32_t now = ms_tick;

    if ((now - last_rotation_ms) < BTN_ROTATION_LOCKOUT_MS)
    {
        /* Inside lockout: clear btn_state and reset debounce so the button
         * starts clean when the lockout window expires. */
        btn_state          = 0;
        btn_raw_last       = raw;
        btn_last_change_ms = now;
        return;
    }

    if (raw != btn_raw_last)
    {
        btn_raw_last       = raw;
        btn_last_change_ms = now;
    }

    if ((now - btn_last_change_ms) >= BTN_DEBOUNCE_MS)
        btn_state = raw;
}


/* ═══════════════════════════════════════════════════════════════════════════
 * MAIN
 * ═══════════════════════════════════════════════════════════════════════════ */

int main(void)
{
    SystemInit();
    iwdg_init();          /* hardening C: hang -> warm reset -> stage-1 counts it */
    tim2_init();
    encoder_gpio_init();

    /* Seed initial encoder state before enabling EXTI */
    enc_last_ab = read_enc_ab();

    exti_encoder_init();
    calc_backoff();

    __enable_irq();

    while (1)
    {
        uint32_t now = ms_tick;
        iwdg_kick();          /* every loop iteration; nothing here blocks > 2 s */

        /* ── Enumeration state machine ─────────────────────────── */

        if (dev_state == DEV_BOOT_WAITING && now >= backoff_ms)
        {
            enum_ready_start_ms = now;
            i2c_slave_init(ENUM_ADDR);
            dev_state = DEV_ENUM_READY;
        }

        if (dev_state == DEV_ENUM_READY && (now - enum_ready_start_ms) > 200)
        {
            I2C1->CTLR1 &= ~I2C_CTLR1_PE;
            backoff_ms = calc_rebackoff_ms();
            dev_state  = DEV_BOOT_WAITING;
        }

        if (dev_state == DEV_ASSIGNING)
        {
            i2c_switch_addr(new_addr);
            dev_state = DEV_ASSIGNED;
            BOOT_ATTEMPT_CELL = 0;   /* healthy: I2C works, enumeration done */
        }

        /* ── Normal operation ──────────────────────────────────── */

        poll_button();

        if (dev_state == DEV_ASSIGNED)
        {
            if (cmd_ready)
            {
                cmd_ready = 0;
                process_command();
            }
        }
    }
}

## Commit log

2026-05-08 Create hardware/kicad folder
2026-05-08 Add Kicad project files
    [I2C_RotaryEncoder.kicad_pcb, I2C_RotaryEncoder.kicad_sch]
2026-05-08 Add schematics
2026-05-08 Upload PCB images
2026-06-01 Add knob firmware v1.0 - dynamic I2C enumeration, quadrature encoder, button
2026-06-01 Fix phantom button presses: rotation lockout 150ms + debounce 50ms
    [knob_firmware.c]
2026-06-01 v1.2: EXTI interrupts for encoder; button forced-0 during rotation lockout
2026-06-01 v1.3: fix encoder A/B swap and active-low polarity (per Wagiminator reference)
    [knob_firmware.c]
2026-06-01 v1.4: fix button pin - PC4 not PD6; remove erroneous GPIOD init
    [knob_firmware.c]
2026-06-01 Update README: complete pinout, firmware v1.5 protocol, Python driver docs
2026-06-01 fix: clear enc_delta atomically in ISR to prevent race condition on fast rotation
    [knob_firmware.c]
2026-06-09 Firmware: bootloader-hosted build (I2C OTA)
    - Relink application at 0x1000 via app.ld (FLASH 0x1000/len 0x2C00,
    RAM 2032B so the bootloader handoff cell @0x200007F0 is protected)
    - Add 0xB0 ENTER_BOOTLOADER command: write magic 0x6E6B4231 to the
    handoff cell + NVIC_SystemReset() -> drops into the I2C bootloader
    - Makefile: LINKER_SCRIPT := app.ld, default target = build
    - All existing module logic unchanged
    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
2026-06-09 Add released firmware binary to firmware/bin
    Track the distributable offset-linked app image (flashed over I2C by the
    Pico). Adds a .gitignore exception so firmware/bin/*.bin is versioned while
    build artifacts elsewhere stay ignored.
2026-06-23 chore: remove redundant hardware/kicad/.keep (folder now has content)
2026-07-05 mechanical: add housing.json (housing profile v1 scaffold)
    Round shaft hole (EC11); clearance heights + shaft position TODO.
2026-07-06 mechanical: knob housing profile from production files
    Board 20x20; JST J1/J2 + M2 mounting identical to the buzzer -> buzzer housing
    template applies directly (connectors verified, same convention). Payload = EC11
    rotary encoder -> top_feature round_hole. Still needed: EC11 body height
    (clearance_top), true shaft centre (CSV origin is an anchor), shaft/bushing dia.
2026-07-06 mechanical: complete knob profile (EC11 shaft centred, body 7.5)
    Shaft confirmed centred at (10, 10.25), o6 -> o7 hole. clearance_top=7.5
    (EC11E18244AU body height). Profile now fully specified - reuses the buzzer
    housing template with a round-hole top feature instead of a grille.
2026-07-09 housing.json: clearance_top 7.5->9.0 (wrap O7 bushing), hole O7->O7.4
    Stack above PCB (Christopher): 4.5 base + O7 bushing + O6 shaft; plate at 9 mm.
2026-07-09 housing.json: M2.5 mounting holes at buzzer-standard diagonal (opposite sockets)
    Holes move to (2.25,2.25)+(17.75,17.75) = opposite the JST sockets (Christopher), so a
    housing holding-column can't land on a socket. Also updates screw M2->M2.5 (board rev to follow).
2026-07-20 Knob hardware V2: remove castellated edges, add status LED + pogo flash pads, remove I2C pull-ups
    - Removed both castellated edge pads (5-pin flash edge + I2C edge); I2C now via JST SH (J1/J2) only
    - New flash interface J3: noknok_FlashPads_I2C-module_1x3_M2.5 pogo pads (GND/SWIO/VCC) with keyed M2.5 hole
    - Added status LED D2 + R5 (2.2k) on PD1/SWIO, active-low, bootloader-driven
    - Removed on-board I2C pull-ups R2/R3 (host-only per ADR)
    - Added second mounting hole H1, diagonally opposite the keyed flash-pad hole
    - R1 (VDD series) stays 10R, no change
    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
    [I2C_RotaryEncoder.kicad_pcb, I2C_RotaryEncoder.kicad_sch, I2C_knob.kicad_pcb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]
2026-07-20 Knob V2: rename status LED resistor R5 -> R2, add BOM
    R5 was renamed to R2 in KiCad (R2/R3 freed up by the removed pull-ups).
    Docs updated to match; added the exported BOM (.xls).
    [I2C_knob.kicad_pcb, I2C_knob.kicad_sch, module_I2C-knob-V2_BOM.xls]
2026-08-25 hardware: update schematic, rename BOM and schematic PDF, fix readme links
    [I2C_knob.kicad_sch, module_I2C-knob-BOM.xls, module_I2C-knob-V2_BOM.xls]
2026-09-01 README: add trademark attribution for Qwiic and STEMMA QT
    The marks were already used adjectivally to state connector
    compatibility, which is permitted referential use - this adds the
    attribution and an explicit non-affiliation line, and corrects the
    capitalisation of STEMMA QT (Adafruit writes it uppercase).
2026-09-11 v2.2.0: DEV-31 hardening C - independent watchdog + boot-attempt handshake with stage-1
    Same change as LED Button v2.3 and buzzer v3.4.0: IWDG (~2 s) started after
    SystemInit and kicked every main-loop iteration; BOOT_ATTEMPT_CELL
    (0x200007F8) cleared the moment an I2C address is assigned.
    Builds (2704 B). NOT individually bench-tested - no knob on the bench today.
    The edit is the identical sed applied to the same template that is
    bench-proven on the LED Button (against stage-1) and the buzzer (running).
    [knob_firmware.c]
2026-09-11 README: v2.2.0 — version strings + changelog (watchdog + boot-health handshake, DEV-31)
2026-09-11 v2.3.0: relink at 0x1400 (bootloader layout 2, stage-1 grows to 4 KB)
    No behaviour change. Built on the Pi from this source; the .bin is the layout-2 image. Not compatible with the legacy monolithic bootloader or a layout-1 stage-1 (DEV-31).
    [knob_firmware.c]
2026-09-11 Add firmware/index.json (current-firmware index)
    Declares the current firmware for this module in the same commit as the
    binary, so the version and the bytes cannot drift apart. Product manifests
    now carry only a floor (min); the brain reads this file to decide what to
    install, and requires_bootloader tells it when an image is NOT installable
    on the module in front of it.
    Spec: Ecosystem/software/firmware-index.md
    Registry: Ecosystem/software/modules.json
2026-10-04 housing.json: print-tuned values from the 2026-10-03 housing print (see notes)
2026-10-05 housing.json: shaft hole 7.5 (second housing print)
